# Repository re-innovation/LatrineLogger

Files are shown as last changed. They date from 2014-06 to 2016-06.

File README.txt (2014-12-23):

This is the github repository for the Latrine Logger.

This work has been done by James Fowkes, Nicola Greene and Matt Little from Renewable Energy Innovation.

Contact:
www.re-innovation.co.uk
matt@re-innovation.co.uk

Overview:

This is a prototype unit developed for Water For People to monitor the use of pit latrines in various locations in Uganda.
This is based upon the DataDuino datalogging platform, but with some changes.
A 555 timer based capacitance to frequency unit is used to detect a 'flush'
The duration of the flush is measured and written, along with a date and time-stamp, to an SD card.
This is all based upon an ATmega328 programmed with the Arduino bootloader.
Code has been written for the Arudino IDE.

see www.re-innovation.co.uk for more details

The Arduino files are include a library and a full sketch.
The files are:
libaries/LatrineSensor which needs to go in your Arduino libraries folder. This includes an example.
LatrineLogger is the full sketch for data logging. 

Previous commits in this repository include the Arduino code as a ZIP file.

The code also requires the following third-party Arduino libraries:
Rtc_Pcf8563 (http://playground.arduino.cc/Main/RTC-PCF8563)
SdFat (https://github.com/greiman/SdFat)

Both of these must exists in your Arduino libraries folder.

Files in the repository:
	
	Readme
	PCB files for KiCAD
	Instructions
	Arduino code

Modified:

To Do:

Upload the PCB files

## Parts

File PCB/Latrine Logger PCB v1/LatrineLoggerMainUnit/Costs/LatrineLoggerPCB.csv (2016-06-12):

ref | value
BT1 | CR2032 3V BATT
C1 | 100uF
C2 | 100nF
C3 | 100nF
C4 | 22pF
C5 | 22pF
C6 | 10uF
C7 | CTRIM
C8 | 4.7uf
C9 | >10uf
C10 | 1uf
C11 | 10uf
C12 | 10uF
C13 | 10uF
C14 | 10uf
D1 | D13
D2 | DATA
D3 | 1N4001
D4 | 1N4148
D5 | 1N4148
IC1 | ATMEGA328P-P
J1 | CON-SD-MMC-3
K1 | CONN_3
K2 | CONN_3
K3 | CONN_3
K4 | CONN_3
K5 | CONN_3
K6 | CONN_3
L1 | 10uH
P1 | CONN_1
P2 | CONN_1
P3 | CONN_1
P4 | CONN_1
P5 | BATTERY
P6 | SOLAR
P7 | A_IN_0
P8 | A_IN_1
P9 | A_IN_2
P10 | A_IN_3
P11 | PWR_JMP
P12 | ISP
P13 | FTDI
P14 | SERIAL
P15 | SIM900 GSM
R1 | 470k
R2 | 100k
R3 | THERM
R4 | 100k
R5 | 1k
R6 | 1k
R7 | 10k
R8 | 10k
R9 | 10k
R10 | 10k
R11 | 40.2k
R12 | 1020k
R13 | 332k
SHIELD1 | ARDUINO_SHIELD
SW1 | CALIBRATE
SW2 | RESET
U1 | 4050
U2 | PCF8563
U3 | LTC3105_MSOP
U4 | MCP1703
X1 | 16MHz
X2 | 32.27 kHz

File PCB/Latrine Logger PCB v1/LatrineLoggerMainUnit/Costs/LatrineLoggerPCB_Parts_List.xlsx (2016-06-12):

Reference | Value | Info | Package | Supplier | Code | Cost (ex VAT) | Link | Ordered?
BT1 | CR2032 3V BATT |  | Through Hole | Toby | BH001-PBSR-LF | £0.40 | http://www.toby.co.uk/content/catalogue/products.aspx?series=BH-001-xxx+%26+BH-008-xxx
C1 | 100uF |  | SMD 6.3mmx5mm | RS | 737-9631 | £0.07 | http://uk.rs-online.com/web/p/aluminium-capacitors/7379631/
C2 | 100nF |  | SMD 0805 | RS | 698-3541 | £0.01 | http://uk.rs-online.com/web/p/ceramic-multilayer-capacitors/6983541/
C3 | 100nF |  | SMD 0805 | RS | 698-3541 | £0.01 | http://uk.rs-online.com/web/p/ceramic-multilayer-capacitors/6983541/
C4 | 22pF |  | SMD 0805 | RS | 4646587 | £0.02 | http://uk.rs-online.com/web/p/ceramic-multilayer-capacitors/4646587/
C5 | 22pF |  | SMD 0805 | RS | 4646587 | £0.02 | http://uk.rs-online.com/web/p/ceramic-multilayer-capacitors/4646587/
C6 | 10uF |  | SMD 4mmx5.5mm | RS | 737-9625 | £0.04 | http://uk.rs-online.com/web/p/aluminium-capacitors/7379625/
C7 | CTRIM |  | Through Hole
C8 | 4.7uf |  | SMD 4mmx5.5mm | RS | 7379656 | £0.05 | http://uk.rs-online.com/web/p/aluminium-capacitors/7379656/
C9 | >10uf |  | SMD 4mmx5.5mm | RS | 737-9625 | £0.04 | http://uk.rs-online.com/web/p/aluminium-capacitors/7379625/
C10 | 1uf |  | SMD 0805 | RS | 723-6067 | £0.02 | http://uk.rs-online.com/web/p/ceramic-multilayer-capacitors/7236067/
C11 | 10uf |  | SMD 4mmx5.5mm | RS | 737-9625 | £0.04 | http://uk.rs-online.com/web/p/aluminium-capacitors/7379625/
C12 | 10uF |  | SMD 4mmx5.5mm | RS | 737-9625 | £0.04 | http://uk.rs-online.com/web/p/aluminium-capacitors/7379625/
C13 | 10uF |  | SMD 4mmx5.5mm | RS | 737-9625 | £0.04 | http://uk.rs-online.com/web/p/aluminium-capacitors/7379625/
C14 | 10uf |  | SMD 4mmx5.5mm | RS | 737-9625 | £0.04 | http://uk.rs-online.com/web/p/aluminium-capacitors/7379625/
D1 | D13 |  | SMD 0805 | RS | 6920931 | £0.05 | http://uk.rs-online.com/web/p/visible-leds/6920931/
D2 | DATA |  | SMD 0805 | RS | 6920931 | £0.05 | http://uk.rs-online.com/web/p/visible-leds/6920931/
D3 | S1K-13-F | 800V 1A diode | SMA | RS | 7514761 | £0.08 | http://uk.rs-online.com/web/p/switching-diodes/7514761/
D4 | 1N4148 |  | SOD-323 | RS | 7003677 | £0.05 | http://uk.rs-online.com/web/p/switching-diodes/7003677/
D5 | 1N4148 |  | SOD-323 | RS | 7003677 | £0.05 | http://uk.rs-online.com/web/p/switching-diodes/7003677/
IC1 | ATMEGA328P-P |  | DIP 28 pin Through Hole???
 |  |  | TQFP SMD package | RS | 6963092 | £2.28 | http://uk.rs-online.com/web/p/microcontrollers/6963092/
J1 | CON-SD-MMC-3 |  | SD-MMC SMD | Toby (also Mouser) | SD-RSMT-2-MQ | £1.59 | http://www.toby.co.uk/content/catalogue/products.aspx?series=SD-RSMT-2-MQ
K1 | CONN_3 |  | Connector only
K2 | CONN_3 |  | Connector only
K3 | CONN_3 |  | Connector only
K4 | CONN_3 |  | Connector only
K5 | CONN_3 |  | Connector only
K6 | CONN_3 |  | Connector only
L1 | 10uH | 300mA??? | SMD 1210 | RS | 481-1882 | £0.16 | http://uk.rs-online.com/web/p/wire-wound-surface-mount-inductors/4811882/
P1 | CONN_1 |  | 3mm Mounting Hole
P2 | CONN_1 |  | 3mm Mounting Hole
P3 | CONN_1 |  | 3mm Mounting Hole
P4 | CONN_1 |  | 3mm Mounting Hole
P5 | BATTERY | Conenctor | Screw terminal |  |  | £0.10
 |  |  | JST 2.0mm 2 way | Rapid | 22-5220 | £0.09 | http://www.rapidonline.com/cables-connectors/2-way-top-entry-shrouded-header-2-00mm-22-5220
P6 | SOLAR | Connector | Screw terminal |  |  | £0.10
 |  |  | JST 2.0mm 2 way | Rapid | 22-5220 | £0.09 | http://www.rapidonline.com/cables-connectors/2-way-top-entry-shrouded-header-2-00mm-22-5220
P7 | A_IN_0 |  | Connector only
P8 | A_IN_1 |  | Connector only
P9 | A_IN_2 |  | Connector only
P10 | A_IN_3 |  | Connector only
P11 | PWR_JMP |  | 2 way header pin |  |  | £0.02
P12 | ISP |  | 3x2 Header Pin |  |  | £0.05
P13 | FTDI |  | 6 way header pin |  |  | £0.05
P14 | SERIAL |  | 6 way header pin |  |  | £0.05
P15 | SIM900 GSM |  | 8 way connector.
R1 | 470k |  | SMD 0805 | Farnell | 2073786 | £0.01
R2 | 100k |  | SMD 0805 | Farnell | 2073613RL | £0.01
R3 | THERM |  | SMD 0805 | Farnell | 2103179 | £0.20
R4 | 100k |  | SMD 0805 | Farnell | 2073613RL | £0.01 | http://uk.rs-online.com/web/p/surface-mount-fixed-resistors/2230691/
R5 | 1k |  | SMD 0805 | Farnell | 9234004RL | £0.01
R6 | 1k |  | SMD 0805 | Farnell | 9234004RL | £0.01
R7 | 10k |  | SMD 0805 | Farnell | 2073612RL | £0.01
R8 | 10k |  | SMD 0805 | Farnell | 2073612RL | £0.01
R9 | 10k |  | SMD 0805 | Farnell | 2073612RL | £0.01
R10 | 10k |  | SMD 0805 | Farnell | 2073612RL | £0.01
R11 | 40.2k |  | SMD 0805 | Farnell | 2447658 | £0.01
R12 | 1020k |  | SMD 0805 | Farnell | 2139122RL | £0.01
R13 | 332k |  | SMD 0805 | Farnell | 2139068RL | £0.01
SHIELD1 | ARDUINO_SHIELD |  | 2 x 6W and 2 x 8W connector only
SW1 | CALIBRATE |  | Through hole switch | Rapid | 78-3760 | £0.18 | http://www.rapidonline.com/Electronic-Components/Spdt-Miniature-Slide-Switch-6-Volt-78-3760
SW2 | RESET |  | Tactile switch | Rapid | 78-1120 | £0.11 | http://www.rapidonline.com/electronic-components/4-3mm-miniature-rectangular-tactswitch-78-1120
U1 | 74HC4050 |  |  | RS | 4836544 | £0.14 | http://uk.rs-online.com/web/p/buffer-line-driver-combinations/4836544/
U2 | PCF8563 |  |  | RS | 4368300 | £1.08 | http://uk.rs-online.com/web/p/real-time-clocks/4368300/
U3 | LTC3105_MSOP |  |  | Farnell | 1898601 | £4.91 | http://uk.farnell.com/linear-technology/ltc3105ems-pbf/ic-dc-dc-convertor-msop-12/dp/1898601
U4 | MCP1703 | Check 3.3V!! | SOT23 | RS | 6694907 | £0.35 | http://uk.rs-online.com/web/p/low-dropout-voltage-regulators/6694907/
X1 | 16MHz |  | HC-49-US SMD | RS | 703-7129 | £0.30
X2 | 32.27 kHz |  | Through Hole | Rapid | 90-3046 | £0.17 | http://www.rapidonline.com/electronic-components/32-768khz-12-5pf-3x8mm-radial-cylindrical-watch-crystal-90-3046
 |  |  |  |  | PCB | £2.00
 | PCB + components |  |  |  |  | £15.19
 | 555 Timer Sensor |  |  | Matt |  | £5.00
 | SD Card | 4GB |  | CPC |  | £5.00
 | Solar module | 1W 5V |  | Elecrow | PS0155GE | £3.00 | http://www.elecrow.com/solar-panel-1w-55v-p-794.html
 | LiIon Battery | 2200mAh 3.7V 2.0mm JST connector |  | SeeedStudio |  | £9.90 | http://www.seeedstudio.com/depot/Polymer-Lithium-Ion-Battery-2200mAh-37V-p-1709.html?cPath=1_3
 | 3 x D cell Battery |  |  | Rapid | 18-0151 | £0.88 | http://www.rapidonline.com/electrical-power/3-x-d-battery-holder-tags-18-0151
 | Enclosure | >IP 65 | Fit everything? | CPC |  | £5.00
 | Cable gland | For sensor |  | CPC |  | £0.30
 | Cable gland | For PV |  | CPC |  | £0.30
 |  |  |  | Total (ex VAT) |  | £44.57
 |  |  |  | Total (inc VAT) |  | £53.48

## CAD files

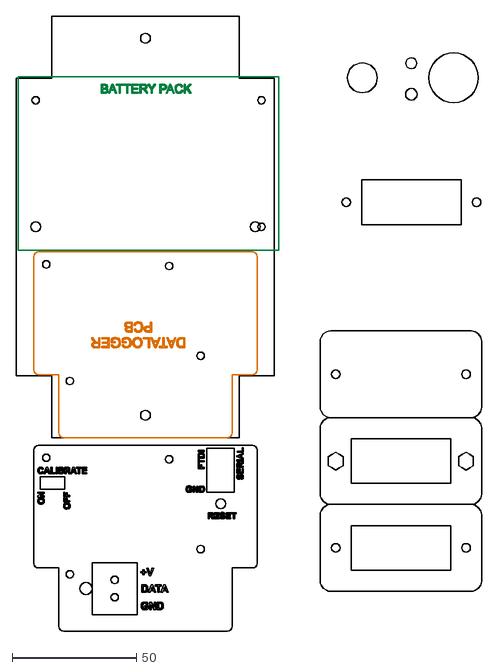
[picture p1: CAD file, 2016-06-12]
Hardware/2015_12_22_Latrine_Logger_Baseplate.dxf
187.5 x 247.9

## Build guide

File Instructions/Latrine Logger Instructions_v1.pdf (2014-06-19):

## Latrine Logger - Data Acquisition Unit

Date: | 19/06/14 | Version: | 1.0 | By: | Matt Little

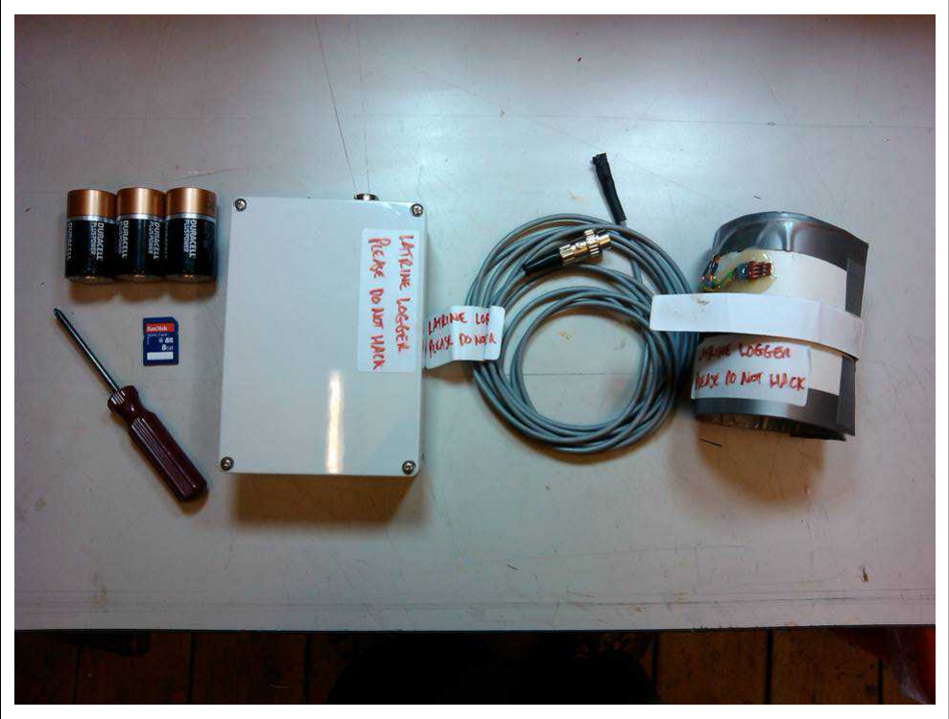
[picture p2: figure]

The LatrineLoggger is an Arduino data acquisition unit which stores data to an SD card (as a .csv file). It uses a real time clock with a back-up battery for accurate data logging and time-stamping.
It uses a 555 timer circuit with a capacitance sensor to read when 'flushes' occur in a plastic pipe.
The change in capacitance is detected and the length of the flush is measured.
This data is written to an SD card in human readable format for analysing later.

It is designed to be low-cost, robust and easy to install.

This was developed by James Fowkes, Nicola Greene and Matt Little for Water For People.

It utilises an Arduino UNO brain.

Note: This requires an FTDI USB to serial 3V3 cable for programming.
Note: This requires 3 x D cell batteries and an SD card (8Gb size best).

Parts required:

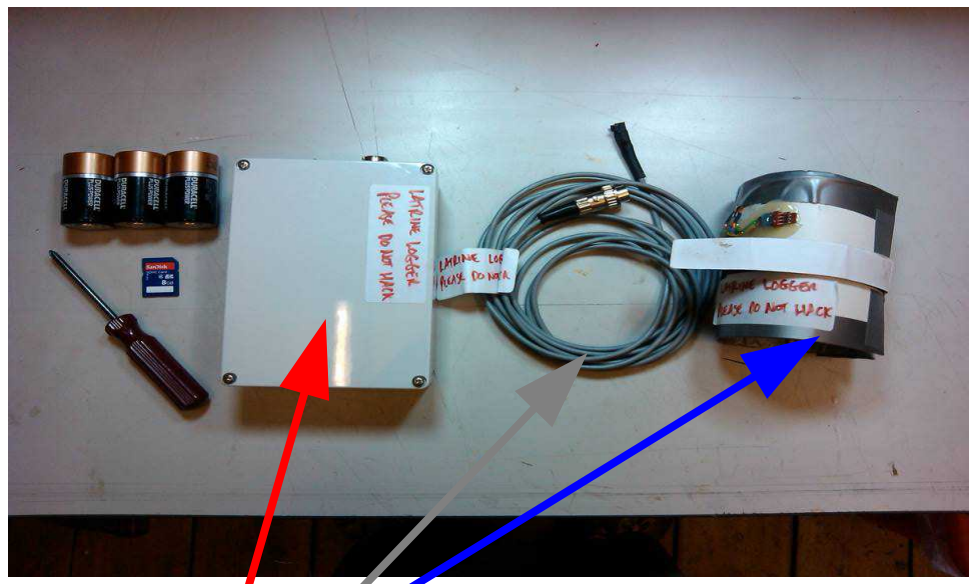
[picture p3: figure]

There are three main parts:
- The main logger unit
- The sensor
- The sensor cable

You will also need:
- a high quality SD card with a capacity 4Gb or greater.
- 3 x high quality D size batteries
- A Philips/cross-head screwdriver

You may also need (not supplied):
- a computer with the Arduino IDE installed
- a FTDI USB to serial cable with code: TTL-232R-3V3, such as this:

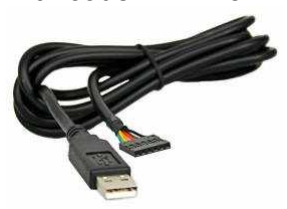
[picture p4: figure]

Available here (among other places): http://www.ftdichip.com/Products/Cables/USBTTLSerial.htm

Installation:

Step: 1 | Wrap the sensor around the waste pipe Unfold the sensor carefully – it contains sensitive electronic connections. Wrap around the waste pipe. Close the velcro strap to ensure a good fit.

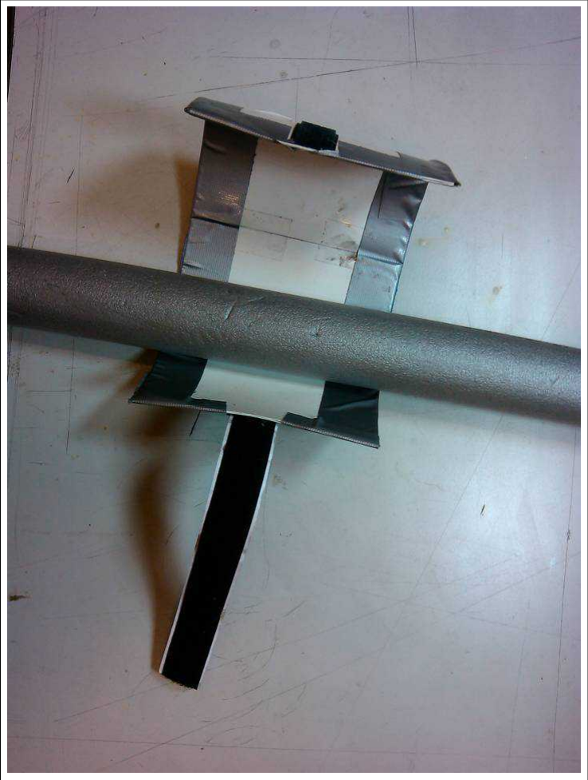
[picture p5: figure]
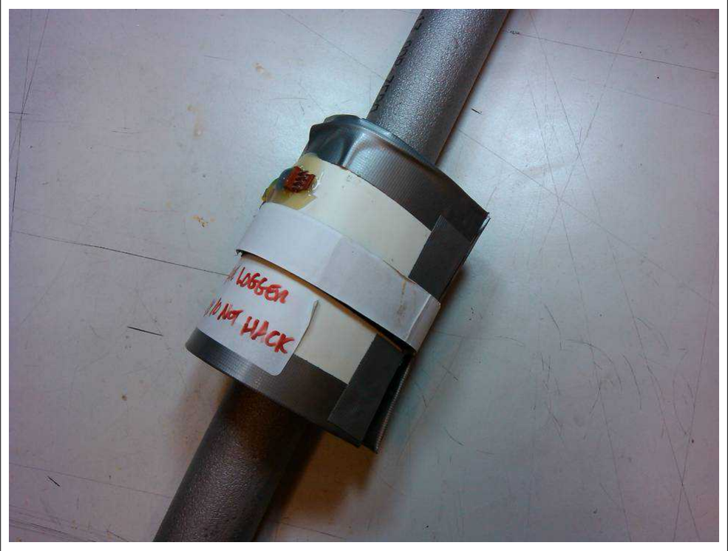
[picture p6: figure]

Step: 2 | Plug in sensor cable

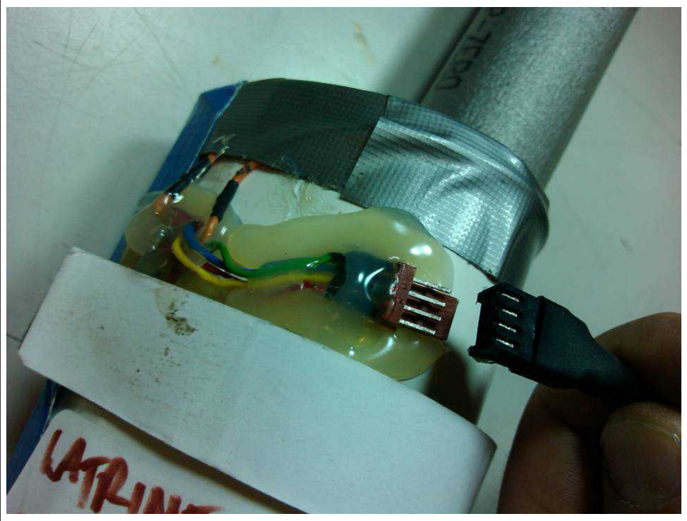
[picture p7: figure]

The sensor cable goes from the sensor to the main logging unit. The plug/socket on the sensor is not great, so please be careful here.

Plug into the main logging unit – ensure the pins match up.

Ensure the locking ring is locked.

Ensure the cable is kept free of any snags and is firmly attached. Use cable ties if possible.

Step: 3 Insert batteries

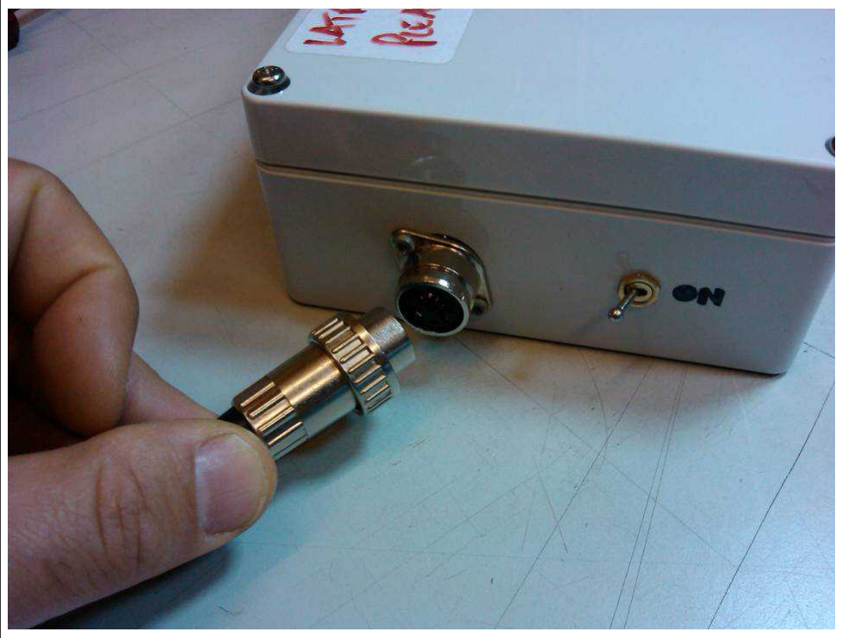
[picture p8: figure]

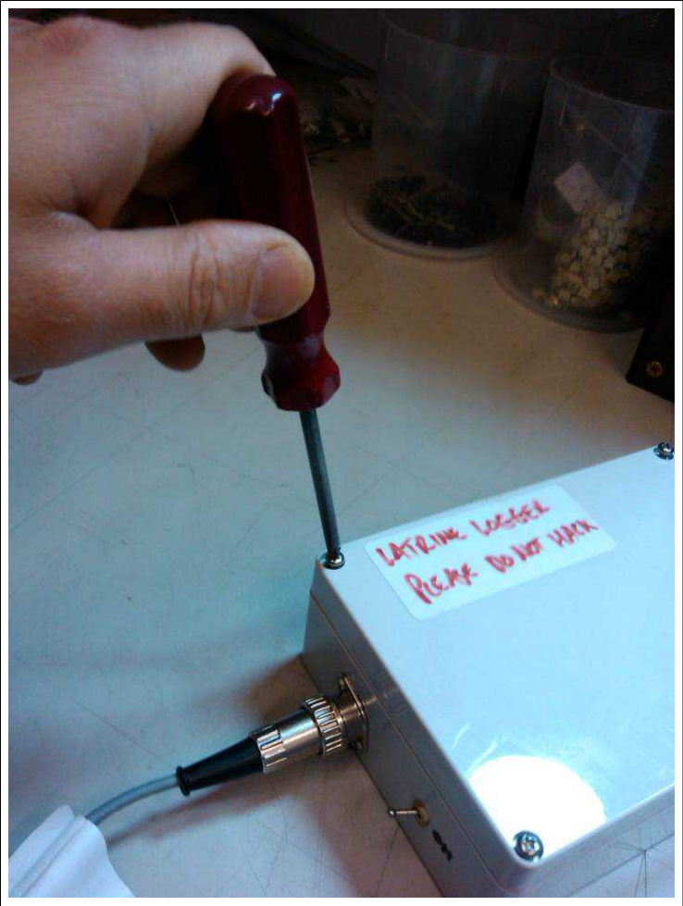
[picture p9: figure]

Open the main logger box with a cross head/Philips screwdriver.

Ensure the unit is switched OFF.

The unit requires 3 x D cell batteries. Use good quality batteries (Duracell, Everready) only.

Ensure correct polarity (check battery boxes)

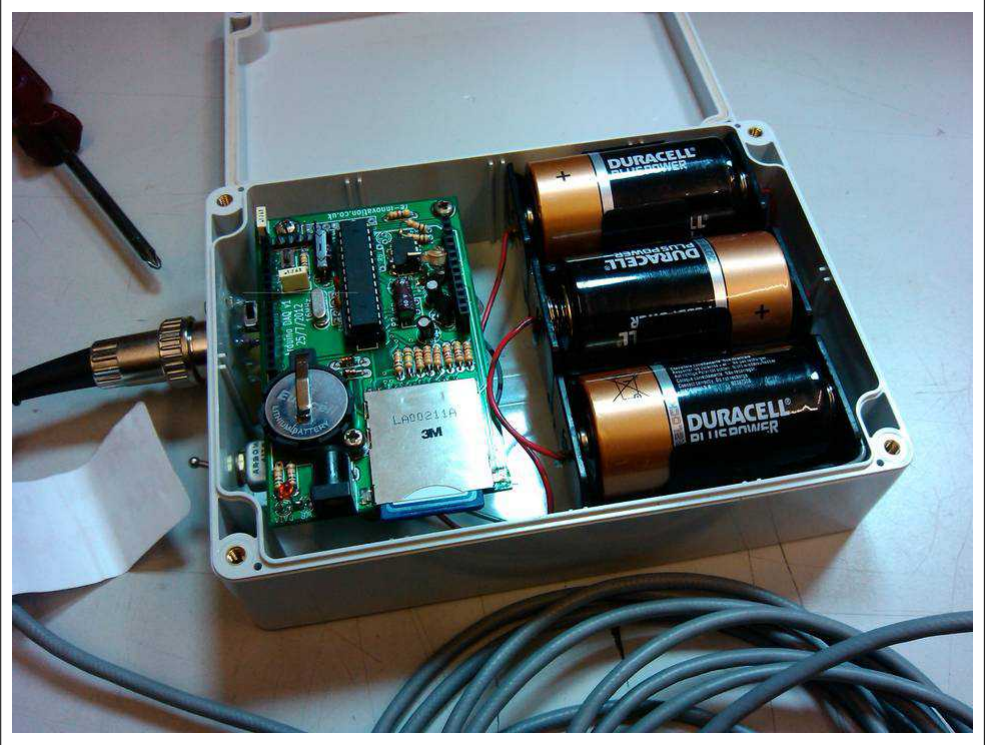
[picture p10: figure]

Step: 4 Insert an SD Card

Use a large volume, good quality card to ensure long life-time.

SD card fits into the SD card holder. Push until it clicks and is held.

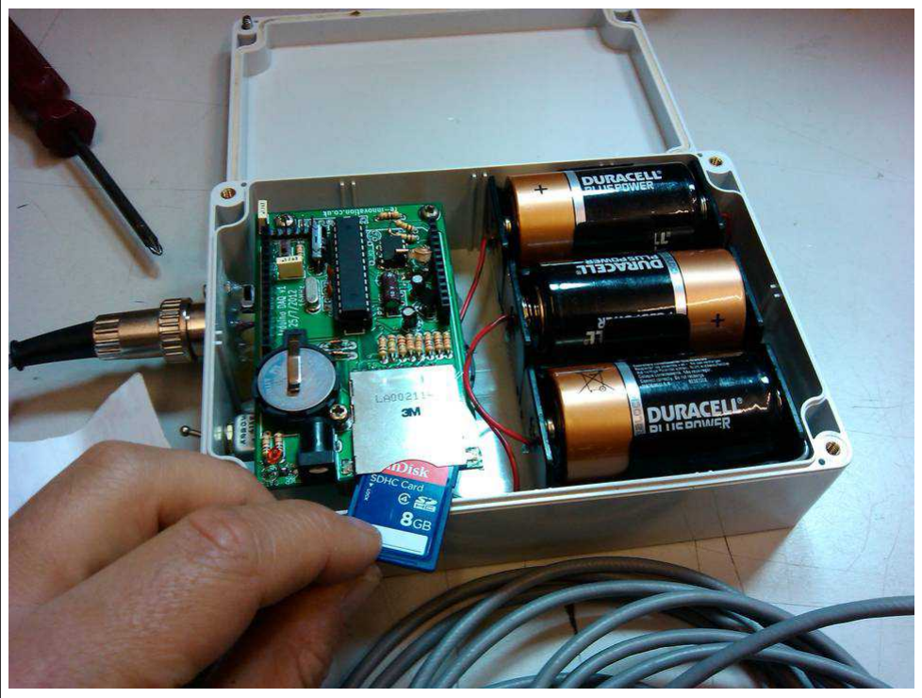
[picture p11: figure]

Step: 5 Switch the unit ON and test Switch the unit ON

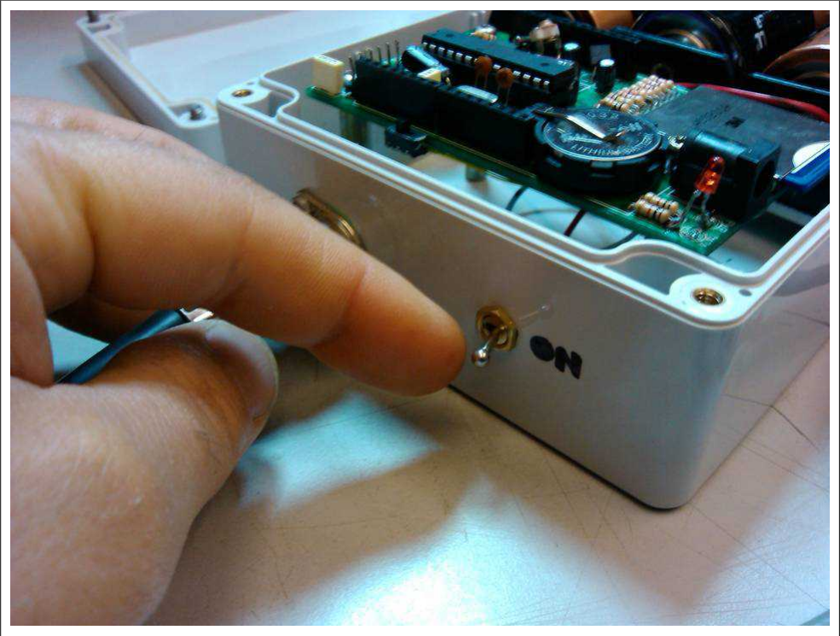
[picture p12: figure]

You should see the red LED flash briefly when switched on.

Pour a decent quantity of water down the waste pipe.

You should see the unit flash when it first senses the flow. It will then flash again, twice, when the flush has ended

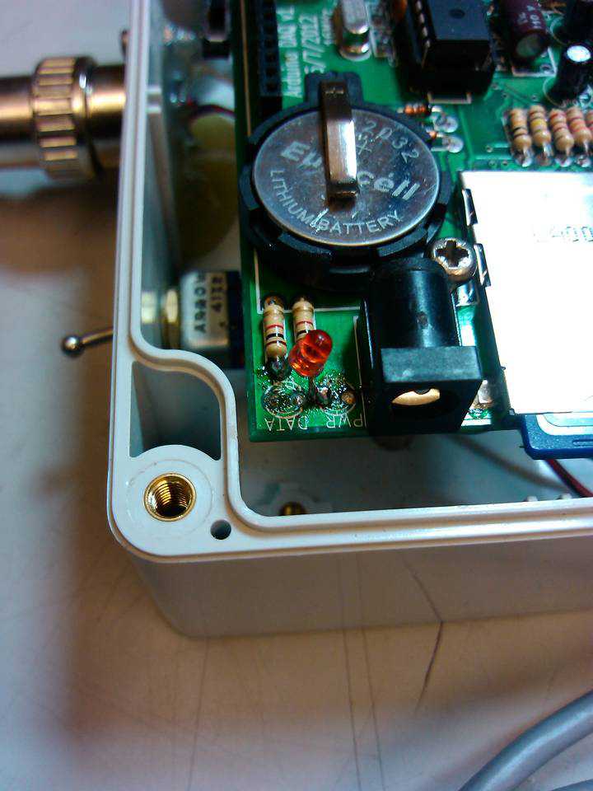
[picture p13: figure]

Step: 6 | Check Data is OK
Follow the 'Data Download' instructions. Check data is being recorded OK. If not: Check cable connected correctly and SD
Step: 7 | Leave to monitor
| Unit should not need any intervention, but checking the data regularly for testing is sensible.

Data download:

Step: 1 | Switch the unit OFF
Its always best to switch the unit OFF when removing or inserting the SD card.

Step: 2 | Remove the SD card
Push the SD card slightly in and it will then release and spring slightly out.

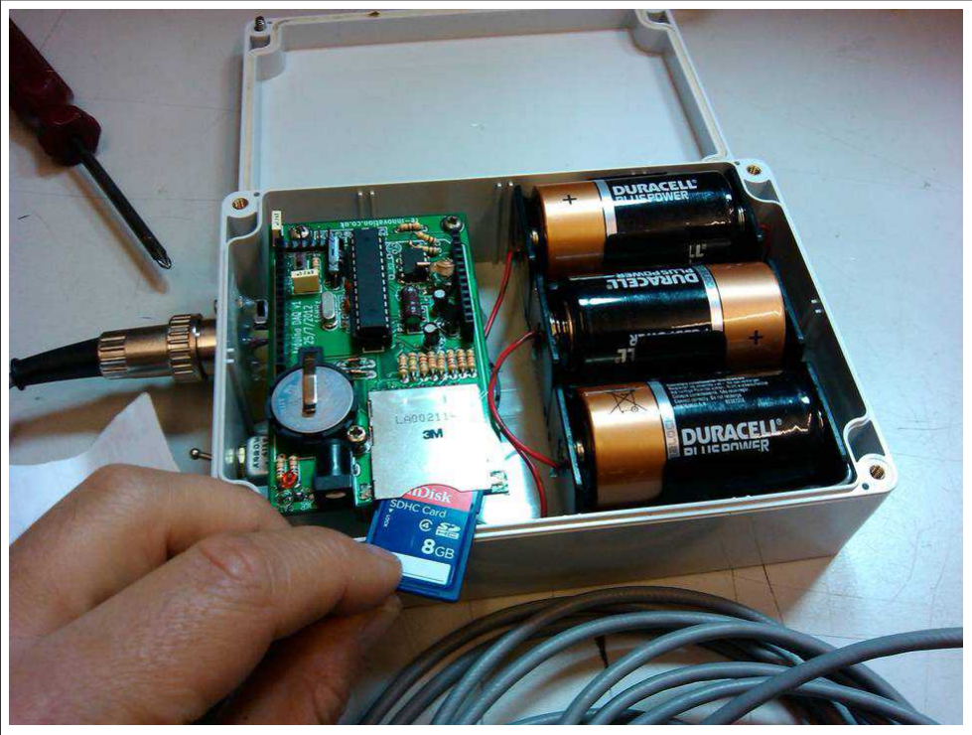
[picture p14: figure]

Step: 3 | Insert the SD card into a computer You might need USB to SD card converter. A lot of computers have them built in.

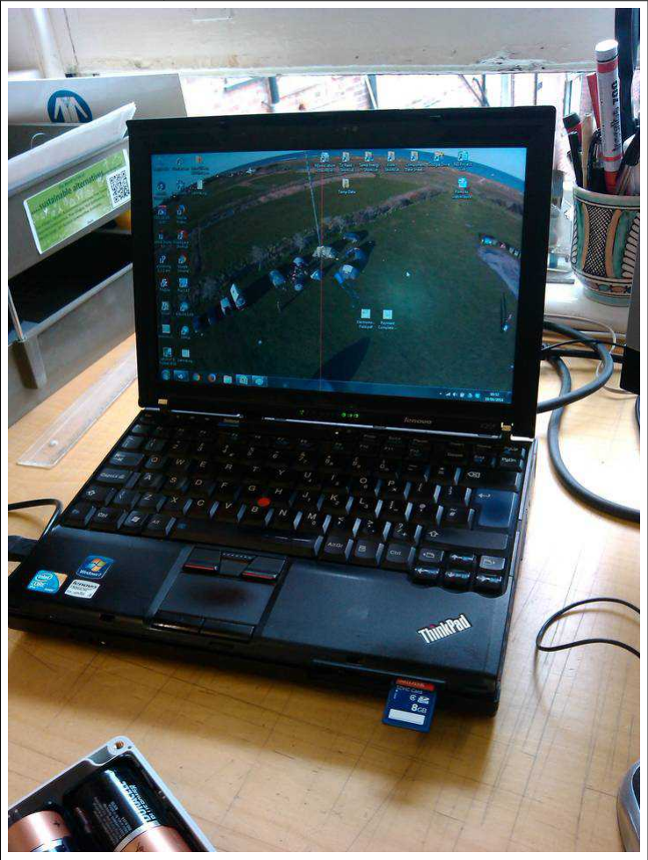
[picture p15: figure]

Step: 4 | Load data

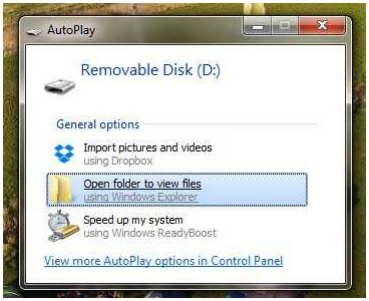
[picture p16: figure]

If using Windows:
You will get a pop up
'AutoPlay' box.

Click on 'Open folder to
view files'

You will see a list of the files (one is created
each day, unless there
was no data).

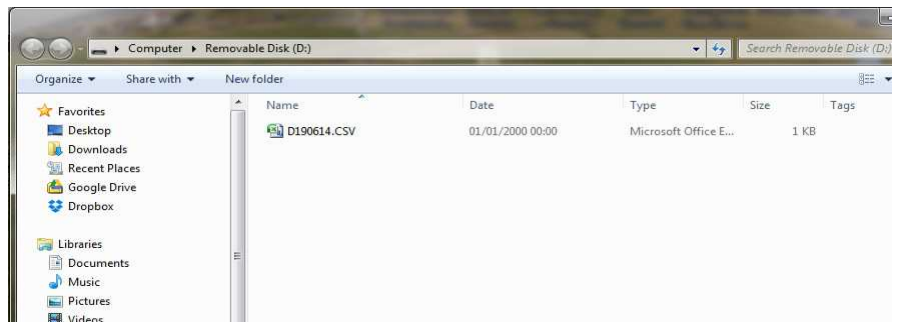
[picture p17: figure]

Step: 5 Check data is valid Double click on the file and it should open with Excel, or some spreadsheet program.

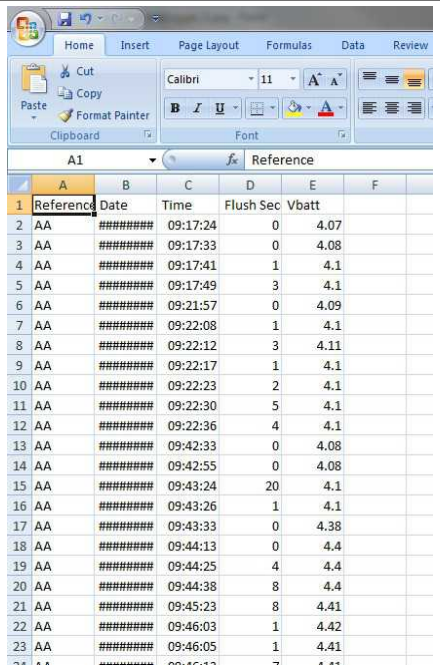
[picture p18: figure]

You can also open the spreadsheet program and navigate to open the file from there.

When the data opens you might see some data is shown as ### symbols. This is due to the fact it is too big for the data holder.

Select everything and then double click on one of the vertical lines. This will auto size the cells and all the data should be visible.

Data is in human-readable format, with the flush time, the duration in seconds and the battery voltage.

If the battery voltage is below 3.3V then the data might not be valid due to power supply issues.

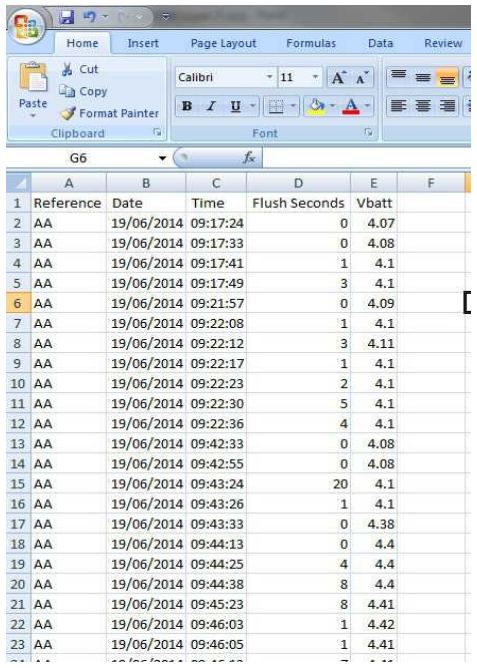
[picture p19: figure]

Step: 6 | Remove SD card
| Always ensure you use the 'Eject Disk' function. Never just remove the disk as this could cause data corruption.

Calibration and setup:
This is more detailed information for changing the time, date and reference and also uploading new programming code into the Arduino. For information only.
Step: 1 | Switch OFF the unit
Step: 2 | Plug in the FTDI cable

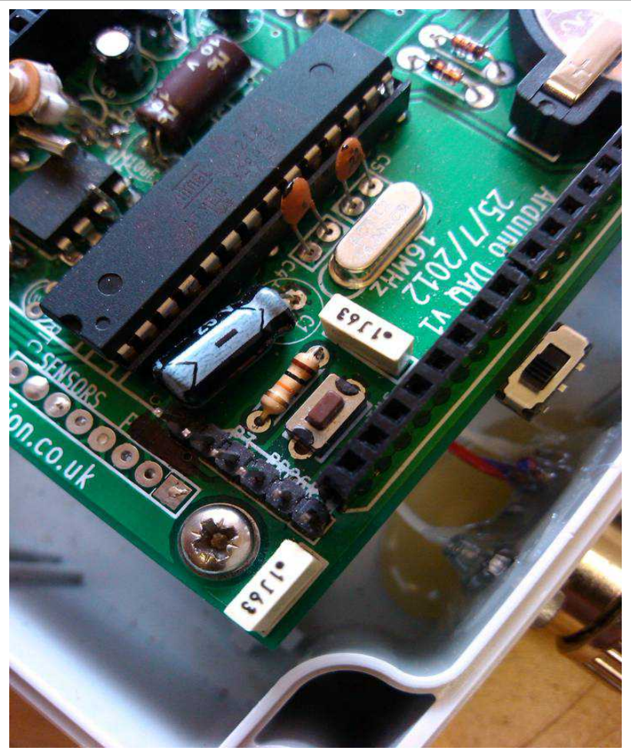
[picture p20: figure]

The FTDI 6 way header plugs into the board into P3 PROGRAM pins. The black lead goes towards the ATMEGA IC, the green wire goes towards the edge of the board.

Step: 3 | Open serial monitor
| Note: This assumes you have installed the Arduino IDE. Click on the 'Serial Monitor' button This will open a new screen. Set the serial baud rate to 115200 in the lower right hand corner.
Step: 4 | Enter Calibrate mode
Flick the calibrate switch ON.

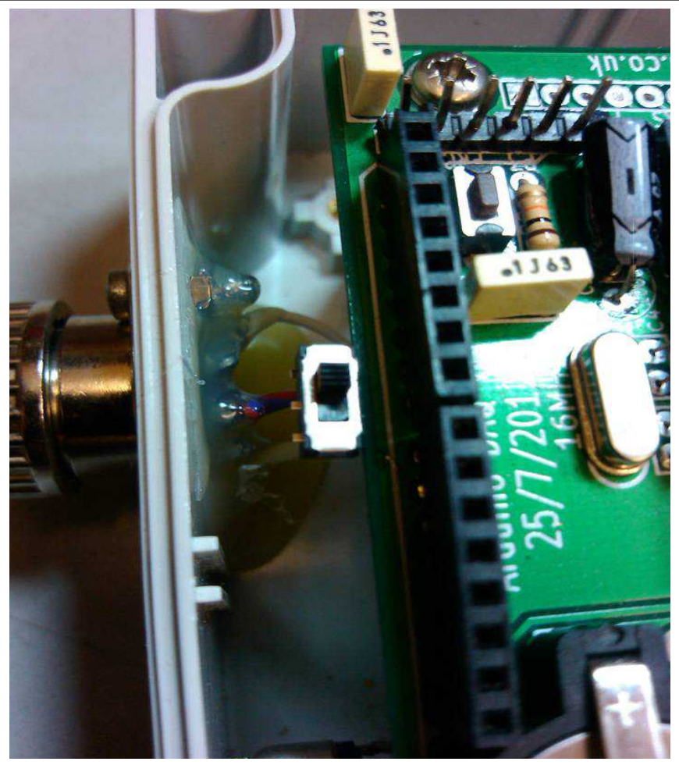
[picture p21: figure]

You will see 'CALIBRATE' written to the serial monitor.
If you do not see this, you are not in calibrate mode and cannot change parameters.

Step: 5 | Change Date
Write DxxxxxxE, where xxxxxx is DDMMYY, DD is the date (eg. 2nd is 02), MM is the month (eg. May is 05) and YY is the year (eg. 2014 is 14) Send this to the device. This will return the correct stored date. Double check this is correct.
Step: 6 | Change Time

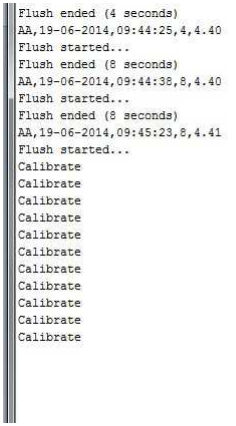
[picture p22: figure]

| Write TxxxxxxE, where xxxxxx is HHMMSS, HH is the hour (eg. 2pm is 14), MM is the minutes (eg. 5 mins past is 05) and SS is the seconds. It is best to set the time to a 'whole' number of seconds slightly in the future (say 14:30:00, when the time is actually 14:29:37), write this into the serial send screen (but do not send). Open a clock on screen and wait until it is exactly 14:30:00. Press send at exactly that moment to update.

This will return the correct stored time. Double check this is correct.

Step: 7 | Change Reference
Write RxxE, where xx is a reference number from 00 to ZZ. This can be done when there are lots of units and you would like to keep a different reference in each one. I would adjust this once, write it on the unit and never change it. This is written into the data, which might be useful for future data processing.

Step: 8 Check data
Switch OFF calibrate mode (set switch back).

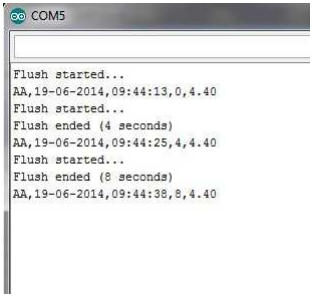
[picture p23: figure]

You can fake a 'flush' by putting your hand into the sensor.
You should see the words 'Flush Started...) when you put your hand in.
When you remove your hand, you should see 'Flush finished. Duration X seconds'.

Then the data written to the SD card will appear as a text string.

The data will appear at 115300 baud to the serial.

Step: 9 | Upload new program
WARNING: Only perform this if you know what you are doing. You can potentially render the unit useless if this is not done correctly. Open the new 'sketch' within the Arduino IDE. Click on the 'Upload' button.

Wait for the Arduino IDE to say 'Done Uploading'

Check the function of the new program, as required.

Technical information:
Please see this list for the Arduino pin allocations:
Pin Number | Type of data | Allocation
D0 | Digital | Serial Rx
D1 | Digital | Serial Tx
D2 | Digital | Clock interrupt at 1 second
D3 | Digital | Available
D4 | Digital | LED indicator
D5 | Digital | 555 timer frequency monitoring
D6 | Digital | SD card - Card detect
D7 | Digital | Calibrate switch
D8 | Digital | Available
D9 | Digital | Available
D10 | Digital | SD card - Chip select - Cannot be used
D11 | Digital | SD card - MOSI - Cannot be used
D12 | Digital | SD card - MISO - Cannot be used
D13 | Digital | SD card - Clock - Cannot be used
A0 | Analogue | Battery Voltage
A1 | Analogue | Available
A2 | Analogue | Available
A3 | Analogue | Available
A4 | Analogue | RTC - SDA - Cannot be used
A5 | Analogue | RTC - SCL - Cannot be used

Arduino code information:
Some example code, including the main Latrine Logger program is available at www.re-innovation.co.uk, (http://www.re-innovation.co.uk/) via the GITHUB account.
Overview of the code:
A PCF8563 Real Time Clock is used to timestamp the data.

Each logger has a reference (user adjustable from 00-99 & AA-ZZ).

Data is written to a .csv file created on an SD card.
A new file is created each day. If file alreay present then data is appended.
The file name is created from the reference number and the date in the format: RXXDXXXX.csv, where RXX is the reference number and DXXXX is the date in the format DDMM.

Data is stored with human readable headers:
"Reference, Time, Date, Flush Duration,Vbattery"

As mentioned in the set-up instructions:
You can adjust the parameters of the device using serial commands. These parameters are stored in EEPROM.
These are:
1. R??E
This will change the reference number to ??
2. T??????E
This will change the time to HHMMSS
3. D??????E
This will change the date to DDMMYY Flow diagram of code:
****TO DO****

Contact details:
Renewable Energy Innovation. info@re-innovation.co.uk
www.re-innovation.co.uk
Hopkinson Gallery
21 Station Street
Nottingham
NG7 6PD

Please email info@re-innovation.co.uk with any questions or comments.

More technical information can be found via www.re-innovation.co.uk. Circuit schematic:

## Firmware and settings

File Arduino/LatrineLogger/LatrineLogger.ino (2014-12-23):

/********************************************************
/****** Latrine Logger **********************************
/****** Based on:      **********************************
/****** DataDuino - Arduino DAQ UNIT ********************
/****** by Matt Little **********************************
/****** Date: 29/5/14 ***********************************
/****** info@re-innovation.co.uk ************************
/****** www.re-innovation.co.uk *************************
/********************************************************

  See www.re-innovation.co.uk for information and construction details
  This implements capacitative sensor for flushes.
  If the sensor is positive then it will record the various data values to an SD card.
  
  This is designed to interface with a sensor unit designed by James Fowkes.
  It is based upon the DataDuino, along with an astable 555 timer circuit.
  
  The 555 timer is counted on pin D5 (Timer1 pin)
  The RTC interrupt is on pin D0 (Interrupt 1)
  The battery voltage is read on A0
  The LED output is attached to pin D4
  A calibrate mode is entered by a switch on pin D7
  
  The LatrineSensor object has a Setup() function that needs to be run in the Arduino setup(). 
  This is where it configures Timer1.
  The library sets up Timer1 to count from the T1 external input. This is Arduino pin 5.
  The library now expects and assumes that its Update() method will be called exactly once per second. 
  If there's significant deviation from that, there will be inaccuracies in the calculations.

/*************Details of Code*****************************

  The DataDuino is an Arduino based SD card datalogger.
  A PCF8563 Realt Time Clock is used to timestamp the data.
  
  
  Data is written to a .csv file created on an SD card.
  A new file is created each day. If file alreay present then data is appended.
  The file name is created from the reference number and the date in the format:
  RXXDXXXX.csv, where RXX is the reference number and DXXXX is the date in the format DDMM. 

  When in calibrate mode:
  You can adjust the parameters of the device using serial commands. These parameters are stored in EEPROM.
  These are:
  R??E
  This will change the reference number to ??
  T??????E
  This will change the time to HHMMSS
  D??????E
  
  Updates: 
  30/10/12 Code written - Matt Little
  31/10/12 writing code description and sorting out new sample timings - Matt Little
  19/9/13  Getting code to work on Arduino 1.0.5 - Matt Little
  19/9/13  Updated the Rtc_Pcf8563 to work with Arduino 1.0.5 - Matt Little
  19/9/13  Changed getData and sortData to 'listen' for serial data - Matt Little
  19/9/13  Removed all references to temperature - not needed - Matt Little
  23/9/13  Changed format of data - Matt Little
  25/1/14  Changed for counting Poo recording unit - Matt Little
  25/1/14  Added Time and Date updating via serial - Matt Little
  25/1/14  MCP1703 3v3 regulator has 2uA I when not in use - no problem - Matt Little
  27/1/14  Added sleep mode and wake up via UART - Matt Little
  16/2/14  Testing with JamesF data unit - Matt Little
  19/2/14  Testing sleep modes current consumption - Matt Little
  19/2/14  Changed data format to include temperatures and duration. Matt Little
  29/5/14  Changed to Capacitance sensor. Matt Little
  18/6/14  Added JamesF code for sleep modes - Matt Little
  18/6/14  Attach output from 555 timer to timer1 input - D5
  18/6/14  Swap LED from Pin D5 to pin D4 (D5 needed by 555 timer)
  18/6/14  Use internal reference for voltage monitorin - Matt Little
  18/6/14  Attach Interrupt for RTC 1 Hz clock - D2?
  18/6/14  RTC 1Hz pulse controls Update() for sensor (MUST be 1Hz)
  18/6/14  Ensure sleep mode does not switch off system clock (what mode?)
 
  To DO:
  Swap resistors for battery voltage measuring
 
 //*********SD CARD DETAILS***************************	
 The SD card circuit:
 SD card attached to SPI bus as follows:
 ** MOSI - pin 11
 ** MISO - pin 12
 ** CLK - pin 13
 ** CS - pin 10
 ** Card detect - pin 6
 
 SD card code details:
 created  24 Nov 2010
 updated 2 Dec 2010
 by Tom Igoe
 
 //************ Real Time Clock code*******************
 A PCF8563 RTC is attached to pins:
 ** A4 - SDA (serial data)
 ** A5 - SDC (serial clock)
 ** D2 - Clock out - This gives a 1 second pulse to record the data
 
 RTC PCF8563 code details:
 By Joe Robertson, jmr
 orbitalair@bellsouth.net
 
**********************************************************************************************************/


/************ External Libraries*****************************/
#include <stdlib.h>
#include <Wire.h>          // Required for RTC
#include <Rtc_Pcf8563.h>   // RTC library
#include <SdFat.h>            // SD card library
#include <avr/pgmspace.h>  // Library for putting data into program memory
#include <EEPROM.h>        // For writing values to the EEPROM
#include <avr/eeprom.h>
#include <avr/sleep.h>
#include <avr/power.h>
#include <LatrineSensor.h>

/************User variables and hardware allocation**********************************************/

LatrineSensor sensor = LatrineSensor(onFlushStart, onFlushEnd);

/******* SD CARD*************/
#define chipSelect 10 // The SD card Chip Select pin 10
#define cardDetect 6  // The SD card detect is on pin 6
// The other SD card pins (D11,D12,D13) are all set within SD.h
int cardDetectOld = LOW;  // This is the flag for the old reading of the card detect

// SD file system object
SdFat sd;
//Log file
SdFile datafile;  

//File datafile;   // The logging file
String dataString;    // This is the holder for the data as a string. Start as blank
int counter = 0;   // Clue is in the name - its a counter.
long dataCounter = 0;  // This holds the number of seconds since the last data store

/*************Real Time Clock*******/
Rtc_Pcf8563 rtc;
#define I2C_RTC 0x51 // 7 bit address (without last bit - look at the datasheet)
#define RTCinterrupt 0  // RTC interrupt - This is pin 2 of ardunio - which is INT0

/********* I/O Pins *************/
#define LEDred 4      // The output led is on pin 4
#define calibrate 7   // This controls if we are in serial calibrate mode or not
#define batteryPin A1  // For monitoring the battery voltage
#define timerPin 5      // The pin for the 555 timer input

///********* Battery Voltage ****************/
float batteryVoltage;        // Temporary store for float
char BatteryVoltStr[5];      // Hold the battery voltage as a string

// ****** Serial Data Read***********
// Variables for the serial data read
char inByte;         // incoming serial char
String str_buffer = "";  // This is the holder for the string which we will display

/********** Thermistor Data Storage ************/
#define thermistor A0  // This is the analog pin for the thermistor
float TempC = 0;  // This holds the converted value of temperature
char TempCStr[6];  // A string buffer to hold the converted string

// enumarating 3 major temperature scales
enum {
  T_KELVIN=0,
  T_CELSIUS,
  T_FAHRENHEIT
};
// Manufacturer data for episco k164 10k thermistor
// simply delete this if you don't need it
// or use this idea to define your own thermistors
//#define EPISCO_K164_10k 4300.0f,298.15f,10000.0f  // B,T0,R0
//#define GT_Thermistor_10k 4126.0f,298.15f,10000.0f  // B,T0,R0
#define Vishay_Thermistor_47k 4090.0f,298.15f,47000.0f  // B,T0,R0

//********Variables for the Filename*******************

char filename[] = "DXXXXXX.csv";  // This is a holder for the full file name
char deviceID[3]; // A buffer to hold the device ID

long sampleTime = 2;  // This is the time between samples for the DAQ
                      // Sample time is stored in EEPROM in locations 2 & 3

volatile boolean writedataflag = HIGH;  // A flag to tell the code when to write data

int flushSeconds=0;    // Holds the number of seconds for the flush

// Varibales for writing to EEPROM
int hiByte;      // These are used to store longer variables into EERPRPROM
int loByte;

// These next ints are for the filename conversion
int day_int =0;      // To find the day from the Date for the filename
int day_int1 =0;
int day_int2 =0;
int month_int = 0;
int month_int1 = 0;
int month_int2 = 0;
int year_int = 0;  // Year
int hour_int = 0;
int min_int = 0;
int sec_int = 0;

boolean calibrateFlag = HIGH;  // This flag is lowered if we are in calibrate mode (switch ON)
boolean debugFlag = LOW;    // Set this if you want to be in debugging mode.

boolean rtcInterrupt = false;

//**********STRINGS TO USE****************************
String comma = ",";
String date;        // The stored date from filename creation
String newdate;     // The new date, read every time 

// These are Char Strings - they are stored in program memory to save space in data memory
// These are a mixutre of error messages and serial printed information
const char headers[] PROGMEM = "Reference, Date, Time, Flush Seconds, Vbatt, Temp";  // Headers for the top of the file
const char headersOK[] PROGMEM = "Headers OK";
const char erroropen[] PROGMEM = "Error opening file";
const char error[] PROGMEM = "ERROR ERROR ERROR";
const char initialisesd[] PROGMEM = "Initialising SD card...";
const char dateerror[] PROGMEM = "Dates are not the same - create new file";
const char reference[] PROGMEM = "The ref number is:";
const char noSD[] PROGMEM = "No SD card present";

#define MAX_STRING 80      // Sets the maximum length of string probably could be lower
char stringBuffer[MAX_STRING];  // A buffer to hold the string when pulled from program memory


/***************************************************
 *  Name:        RTC
 *
 *  Returns:     Nothing.
 *
 *  Parameters:  None.
 *
 *  Description: I use the CLK_OUT from the RTC to give me exact 1Hz signal
 *               To do this I changed the initialise the RTC with the CLKOUT at 1Hz
 *
 ***************************************************/
void RTC()
{ 
  
  // This wakes us up as it detatches the interrupt
  detachInterrupt(RTCinterrupt);
  dataCounter++;
  
  if(writedataflag==LOW&&dataCounter>=sampleTime)  // This stops us loosing data if a second is missed
  {   
    // Reset the DataCounter
    dataCounter = 0;  
  }
  
  rtcInterrupt = true;    // Set the flag true to show it came from this interrupt
}

/***************************************************
 *  Name:        enterSleep
 *
 *  Returns:     Nothing.
 *
 *  Parameters:  None.
 *
 *  Description: Enters the arduino into sleep mode.
 *
 ***************************************************/
void enterSleep(void)
{

  attachInterrupt(RTCinterrupt, RTC, RISING);
  
  sleep_enable();
   
  set_sleep_mode(SLEEP_MODE_IDLE);  
 
   /* Disable all of the unused peripherals. This will reduce power
   * consumption further and, more importantly, some of these
   * peripherals may generate interrupts that will wake our Arduino from
   * sleep!
   */
  power_adc_disable();
  power_spi_disable();
  power_timer0_disable();
  power_timer2_disable();
  power_twi_disable(); 
  
  sleep_cpu();
  /* The program will continue from here. */
  /************* ASLEEP *******************/
  
  // ZZZZZZZZZZZZZZZZZZZZZZZZZZZZZZZZZZZZ //
  
  /************** WOKEN UP ***************/
  /* First thing to do is disable sleep. */
  sleep_disable();
 
   /* Re-enable the peripherals. */
  power_all_enable(); 
}


/***************************************************
 *  Name:        setup
 *
 *  Returns:     Nothing.
 *
 *  Parameters:  None.
 *
 *  Description: Setup for the Arduino.           
 *
 ***************************************************/
void setup()
{
  sensor.Setup(); // MUST be called to start counting!
  Serial.begin(115200);
  Wire.begin();
  
  //******Real Time Clock Set - up********
  // A4 and A5 are used as I2C interface.
  // D2 is connected to CLK OUT from RTC. This triggers an interrupt to take data
  // We need to enable pull up resistors
  pinMode(A4, INPUT);           // set pin to input
  digitalWrite(A4, HIGH);       // turn on pullup resistors
  pinMode(A5, INPUT);           // set pin to input
  digitalWrite(A5, HIGH);       // turn on pullup resistors
  pinMode(2,INPUT);    // Set D2 to be an input for the RTC CLK-OUT   
  //initialise the real time clock
  Rtc_Pcf8563 rtc; 
 
  //initialisetemp();  // Initialise the temperature sensors
  pinMode(LEDred,OUTPUT);    // Set D5 to be an output LED
  digitalWrite(LEDred,LOW);
  pinMode(cardDetect,INPUT);  // D6 is the SD card detect on pin 6.
 
  //Set up digital data lines
  pinMode(calibrate,INPUT_PULLUP);
 
  // Battery voltage sensing
  pinMode(batteryPin,INPUT);
  
  // 555 sensor input
  pinMode(timerPin, INPUT);           // set pin to input
  digitalWrite(timerPin, HIGH);       // turn on pullup resistors
  
  // Put unused pins to INPUT to try and save power...   
  pinMode(9,INPUT);    
  pinMode(A2,INPUT);
  pinMode(A3,INPUT); 
  
  setupRTC();  // Initialise the real time clock  
  
  initialiseSD();    // Inisitalise the SD card   
  createfilename();  // Create the corrct filename (from date)

  // Read the reference number from the EEROM
  deviceID[0] = char(EEPROM.read(0));
  deviceID[1] = char(EEPROM.read(1));
  
  // Read in the sample time from EEPROM
  hiByte = EEPROM.read(2);
  loByte = EEPROM.read(3);
  sampleTime = (hiByte << 8)+loByte;  // Get the sensor calibrate value 
  
  analogReference(EXTERNAL);  // Use 1.1V input for potential divider.
  
  attachInterrupt(RTCinterrupt, RTC, RISING); 
}

/***************************************************
 *  Name:        main loop
 *
 *  Returns:     Nothing.
 *
 *  Parameters:  None.
 *
 *  Description: Main application loop.
 *
 ***************************************************/
void loop()
{
  
  if(writedataflag==HIGH)
  {      
    pinMode(LEDred,OUTPUT);    // Set LED to be an output LED 
    digitalWrite(LEDred, HIGH);   // set the LED ON  

    // *********** BATTERY VOLTAGE ***************************************
    // From Vcc-47k--47k-GND potential divider
    // This is to test in case battery voltage has dropped too low - alert?
    batteryVoltage = float(analogRead(batteryPin))*(3.3/1024.0)*2.0;        // Temporary store for float
    dtostrf(batteryVoltage,2,2,BatteryVoltStr);     // Hold the battery voltage as a string
 
    // *********** TEMPERATURE *****************************************
    // Two versions of this - either with thermistor or I2C sensor (if connected)
    // Thermistor version
    // Get the temperature readings and store to variables
    TempC = Temperature(thermistor,T_CELSIUS,Vishay_Thermistor_47k,47000.0f);
    dtostrf(TempC,2,2,TempCStr);  // Convert the temperature value (double) into a string

    
    // ******** put this data into a file ********************************
    // ****** Check filename *********************************************
    // Each day we want to write a new file.
    // Compare date with previous stored date, every second
    newdate = String(rtc.formatDate(RTCC_DATE_WORLD));  
    if(newdate != date)
    {
       // If date has changed then create a new file
       createfilename();  // Create the corrct filename (from date)
    }    

    // Here we create a data string to write
    // Subtracting '0' converts from ASCII to real number
    // The headers are: "Reference, Time, Date, V, Voltage, I, Current, P, Power"
    dataString =  String(deviceID[0]); 
    dataString += deviceID[1];
    dataString += comma;
    dataString += newdate;
    dataString += comma;
    dataString += String(rtc.formatTime());
    dataString += comma;
    dataString += flushSeconds;
    dataString += comma;
    dataString += BatteryVoltStr;
    dataString += comma;
    dataString += TempCStr;  // Temperature (Thermistor)  
    
    // ************** Write it to the SD card *************
    // This depends upon the card detect.
    // If card is there then write to the file
    // If card has recently been inserted then initialise the card/filenames
    // If card is not there then flash LEDs

    if(digitalRead(cardDetect)==LOW&&cardDetectOld==HIGH)
    {
      delay(100);  // Wait for switch to settle down.
      // There was no card previously so re-initialise and re-check the filename
      initialiseSD();
      createfilename();
    }
    if(digitalRead(cardDetect)==LOW&&cardDetectOld==LOW)
    {
      //Ensure that there is a card present)
      // We then write the data to the SD card here:
      writetoSD();
    }
    else
    {
       Serial.println(getString(noSD));
    }   
    cardDetectOld = digitalRead(cardDetect);  // Store the old value of the card detect
    
    // Finish up write routine here:    
    digitalWrite(LEDred, LOW);   // set the LED OFF  
    writedataflag=LOW;
    Serial.flush();    // Force out the end of the serial data
  }
  
  // Want to check the SD card every second
  if(digitalRead(cardDetect)==HIGH)
  {
    // This meands there is no card present so flash the LED every second
    for(int x=0;x<=5;x++)
    {
      digitalWrite(LEDred, HIGH);   // set the LED ON
      delay(5);
      digitalWrite(LEDred, LOW);   // set the LED ON
      delay(50);     
    }
  } 
  
  // A Switch on D7 will set if the unit is in serial adjust mode or not  
  //calibrateFlag = digitalRead(calibrate);  
  
  if(digitalRead(calibrate)==LOW)
  { 
    
    detachInterrupt(RTCinterrupt);
    rtcInterrupt = false;    
    
    // We ARE in calibrate mode
    Serial.println("Serial Mode");    
    getData();
    delay(1000);  // Some time to read data
    //Serial.flush();    // Force out the end of the serial data
    
//    // Need to check about flushes, even in calibrate mode
//    uint16_t freq = sensor.Update(); // Call once every second
//    Serial.println(freq);     
    
    // Reset all the data collection values
    dataCounter = 0;  
    writedataflag=LOW;
    sensor.Setup(); // MUST be called to start counting!
    
  }
  else
  { 
    // Here we check to see if a flush has been sensed:
    if (rtcInterrupt == true)
    {
      rtcInterrupt = false;
      uint16_t freq = sensor.Update(); // Call once every second
      Serial.println(freq);    
    }
    
    // Then we go to sleep
    attachInterrupt(RTCinterrupt, RTC, RISING); 
    enterSleep();     
  }
  
}

// Set Up RTC routine
void setupRTC()
{
    // This section configures the RTC to have a 1Hz output.
  // Its a bit strange as first we read the data from the RTC
  // Then we load it back again but including the correct second flag  
  rtc.formatDate(RTCC_DATE_WORLD);
  rtc.formatTime();
  
  year_int = rtc.getYear();
  day_int = rtc.getDay();
  month_int = rtc.getMonth();  
  hour_int = rtc.getHour();
  min_int = rtc.getMinute();
  sec_int = rtc.getSecond(); 
  
  Wire.begin(); // Initiate the Wire library and join the I2C bus as a master
  Wire.beginTransmission(I2C_RTC); // Select RTC
  Wire.write(0);        // Start address
  Wire.write(0);     // Control and status 1
  Wire.write(0);     // Control and status 2
  Wire.write(DecToBcd(sec_int));     // Second
  Wire.write(DecToBcd(min_int));    // Minute
  Wire.write(DecToBcd(hour_int));    // Hour
  Wire.write(DecToBcd(day_int));    // Day
  Wire.write(DecToBcd(2));    // Weekday
  Wire.write(DecToBcd(month_int));     // Month (with century bit = 0)
  Wire.write(DecToBcd(year_int));    // Year
  Wire.write(0b10000000);    // Minute alarm (and alarm disabled)
  Wire.write(0b10000000);    // Hour alarm (and alarm disabled)
  Wire.write(0b10000000);    // Day alarm (and alarm disabled)
  Wire.write(0b10000000);    // Weekday alarm (and alarm disabled)
  Wire.write(0b10000011);     // Output clock frequency enabled (1 Hz) ***THIS IS THE IMPORTANT LINE**
  Wire.write(0);     // Timer (countdown) disabled
  Wire.write(0);     // Timer value
  Wire.endTransmission();
}

// Converts a decimal to BCD (binary coded decimal)
byte DecToBcd(byte value){
  return (value / 10 * 16 + value % 10);
}

//*********** FUNCTION TO INITIALISE THE SD CARD***************
void initialiseSD()
{
  // Initialize the SD card at SPI_HALF_SPEED to avoid bus errors 
  // We use SPI_HALF_SPEED here as I am using resistor level shifters.
  //if (!sd.begin(chipSelect, SPI_HALF_SPEED)) sd.initErrorHalt();
  
  // make sure that the default chip select pin is set to
  // output, even if you don't use it:
  pinMode(chipSelect, OUTPUT);
  
  // see if the card is present and can be initialized:
  if (!sd.begin(chipSelect, SPI_HALF_SPEED)) {
    if(debugFlag==HIGH)
    {
      Serial.println("FAIL");
    }
    // don't do anything more:
    // Want to turn on an ERROR LED here
    return;
  }
  else
  {
    if(debugFlag==HIGH)
    {
      Serial.println(getString(initialisesd));
    }
  }
}
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

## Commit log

2014-06-19 Second Commit
    Added instructions and Arduino code
2014-12-19 Updated to latest application and library
    Includes flush end bugfix and configurable sensitivity
    [LatrineLogger.ino]
2015-07-10 Removed Arduino dependencies
2015-07-17 Fixed Arduino compile issue
2015-07-17 Started implementation of TIMER1 overflow capture
2015-07-17 Timer handles overflow interrupt
2016-06-12 Added PCB and hardware
    To link with blog post
    [2015_12_22_Latrine_Logger_Baseplate.dxf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]
